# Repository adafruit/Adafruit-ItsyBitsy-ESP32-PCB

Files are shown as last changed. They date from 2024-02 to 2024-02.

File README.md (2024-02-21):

## Adafruit ItsyBitsy ESP32 8 MB Flash / 2 MB PSRAM PCB

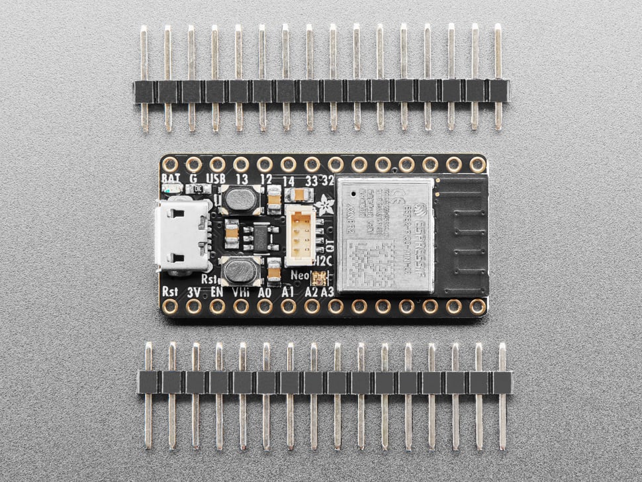
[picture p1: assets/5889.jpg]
<a href="http://www.adafruit.com/products/5889"><br/>
Click here to purchase one from the Adafruit shop</a>

PCB files for the Adafruit ItsyBitsy ESP32 8 MB Flash / 2 MB PSRAM: wFL Antenna and PCB Antenna. 

Format is EagleCAD schematic and board layout
* https://www.adafruit.com/product/5889
* https://www.adafruit.com/product/5890

### Description

What's smaller than a Feather but larger than a Trinket? It's an Adafruit ItsyBitsy ESP32, a powerful processor PCB with a plethora of pins! It features the ESP32 Pico module, an FCC-certified module that contains an ESP32 chip with dual-core 240MHz Tensilica processor, WiFi, and Bluetooth classic + BLE, configured with 8 MB of Flash memory, and 2 MB of PSRAM.

We've added some handy accessories like a USB to serial converter chip, power regulator, USB Micro B, buttons, NeoPixel, and Stemma QT I2C connector to outfit this super-hero chip for any task you want to throw it at. This is also an ultra low power ESP32 board with a deep sleep current consumption of 10uA!

At the core of the Itsy is the ESP32 (PICO ECO V3) chip, which is a single 2.4 GHz Wi-Fi and Bluetooth combo chip designed with TSMC’s 40 nm low-power technology. The ESP32 PICO in particular integrates all peripheral components seamlessly, including a crystal oscillator, flash, PSRAM, filter capacitors, and RF matching links in one single package. This makes it perfect for stuffing into a small space as the ItsyBitsy.

Please note, like other ESP32 modules, the ItsyBitsy ESP32 does not have native USB support - instead, there's a USB to serial converter chip. This means it cannot act like a USB keyboard or mouse, but it does have BLE and BT classic, so you could use it wirelessly.

Here are some of the updates you can look forward to when using ItsyBitsy ESP32:

* Same size, form-factor as the remaining ItsyBitsy mainboards - with a similar but not identical pinout (there are no pins at the end of the board like most other Itsy's due to the radio antenna being there)
* USB Micro B - To maintain compatibility with the rest of the ItsyBitsy's
* ESP32 V2 03 Dual Core 240MHz Xtensa processor - the ESP32 you know and love, with the latest engineering fixes. Massive user base and thousands of existing projects and libraries to use.
* WiFi, Bluetooth LE, and BT Classic for any IoT project usage
* 8 MB Flash & 2 MB PSRAM
* USB to Serial converter built-in with high-speed UART for debugging and uploading, auto-reset circuit works perfectly with any ESP32 uploading tool.
* Can be used with Arduino IDE, CircuitPython or MicroPython
* Built-in RGB NeoPixel LED with power control to reduce quiescent power in deep sleep
* Built-in Red LED on pin D13
* 5V level-shifted output on D5, perfect for driving NeoPixels or other devices that want 5V logic signal
* Battery input pads on the underside with diode protection for external battery packs up to 6V input
* 20 General Purpose "IO" pins:
	* 20 Pads expose pins from the ESP32:
	* 3 are analog input only (A3, A4, A5)
	* 1 is digital output only (5) with 5V level shifted up
	* 13 x 12-bit analog inputs (A0, A1, A2, A3, A4, A5, D12, D13, D14, SDA, SCL, D32, D33)
	* Dual 8-bit analog output DACs on A0/A1
	* PWM outputs on any pin
	* I2C port with STEMMA QT plug-n-play connector - a second I2C port can be defined on any other pins.
	* Hardware UART in addition to the USB-serial UART
	* Hardware SPI on the high speed SPI peripheral pins - a second SPI port can be defined on any other pins.
	* Hardware I2S on any pins
	* 8 x Capacitive Touch with no additional components required
* 3.3V regulator with 600mA peak output
* Light sleep at 4mA, deep sleep at ~10uA
* Reset switch for starting your project code over, for entering bootloader mode or for user reading
* User switch on pin 35
* Really small

Each order comes with one assembled and tested ItsyBitsy ESP32 with headers that can be soldered in for use with a breadboard.

### License

Adafruit invests time and resources providing this open source design, please support Adafruit and open-source hardware by purchasing products from [Adafruit](https://www.adafruit.com)!

Designed by Limor Fried/Ladyada for Adafruit Industries.

Creative Commons Attribution/Share-Alike, all text above must be included in any redistribution. 
See license.txt for additional details.

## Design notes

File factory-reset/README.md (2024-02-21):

## Factory Reset file - ItsyBitsy ESP32 8 MB Flash / 2 MB PSRAM

This is the factory reset file for the ItsyBitsy ESP32 8 MB Flash / 2 MB PSRAM.

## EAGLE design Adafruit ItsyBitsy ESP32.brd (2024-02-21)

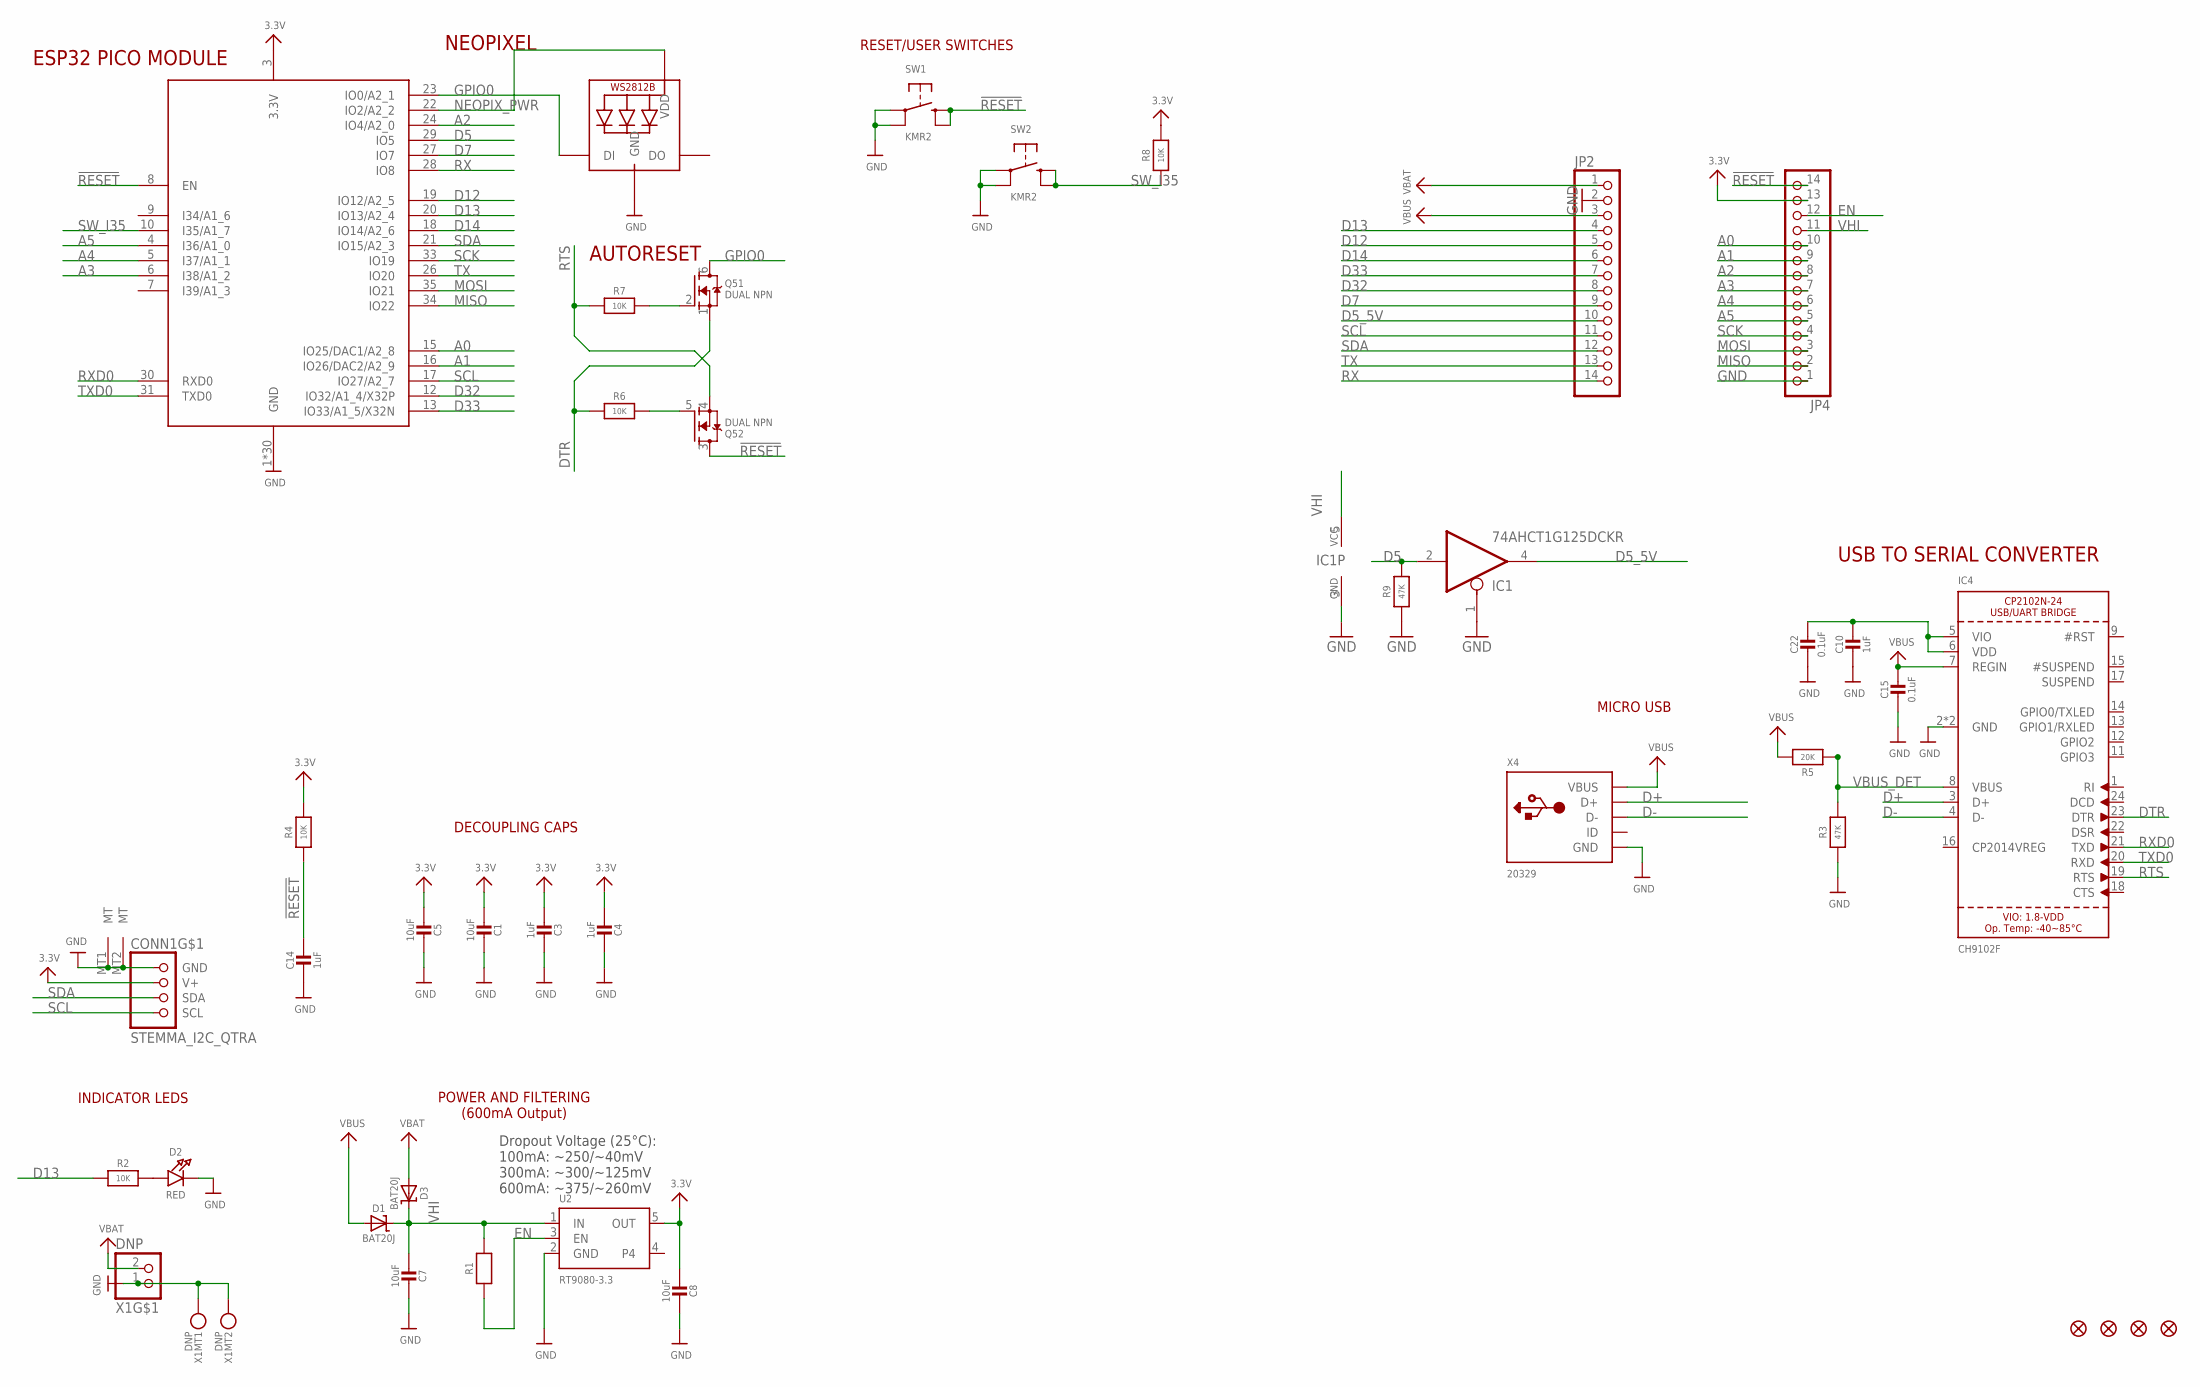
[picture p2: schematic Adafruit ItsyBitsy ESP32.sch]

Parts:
C1, C5, C7, C8: 10uF; 0805-NO
C3, C4, C10, C14: 1uF; 0603-NO
C15, C22: 0.1uF; 0603-NO
CONN1: STEMMA_I2C_QTRA; JST_SH4_RA
D1, D3: BAT20J; SOD-323
D2: RED; CHIPLED_0603_NOOUTLINE
FID1, FID2, FID3, FID4: FIDUCIAL_1MM
IC1: 74AHCT1G125DCKR; SC70-5
IC4: CH9102F; QFN24_4MM_SMSC
JP2, JP4: HEADER-1X14; 1X14_ROUND70
LED2: WS2812B_SK6805_1515; SK6805_1515
Q5: DUAL NPN; SOT363; JLC_ROTATION 0
R1, R2, R4, R6, R7, R8: 10K; 0603-NO
R3, R9: 47K; 0603-NO
R5: 20K; 0603-NO
SW1, SW2: KMR2; BTN_RKB2_4.6X2.8
U2: RT9080-3.3; SOT23-5; JLC_ROTATION 0
X1: DNP; JSTPH2_BATT
X3: ESP32-PICO-MINI-02MINI; ESP32-PICO-MINI
X4: 20329; 4UCONN_20329_SLIM

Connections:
3.3V: C1.2, C3.2, C4.2, C5.2, C8.2, CONN1.2 (V+), JP4.13, R4.2, R8.2, U2.5 (OUT), X3.3 (3.3V)
3.45V: C10.1, C22.1, IC4.5 (VIO), IC4.6 (VDD)
!RESET: C14.1, JP4.14, Q5.3 (D), R4.1, SW1.B (S), SW1.B' (S1), X3.8 (EN)
A0: JP4.10, X3.15 (IO25/DAC1/A2_8)
A1: JP4.9, X3.16 (IO26/DAC2/A2_9)
A2: JP4.8, X3.24 (IO4/A2_0)
A3: JP4.7, X3.6 (I38/A1_2)
A4: JP4.6, X3.5 (I37/A1_1)
A5: JP4.5, X3.4 (I36/A1_0)
D5: IC1.2 (I), R9.2, X3.29 (IO5)
D5_5V: IC1.4 (O), JP2.10
D7: JP2.9, X3.27 (IO7)
D12: JP2.5, X3.19 (IO12/A2_5)
D13: JP2.4, R2.1, X3.20 (IO13/A2_4)
D14: JP2.6, X3.18 (IO14/A2_6)
D32: JP2.8, X3.12 (IO32/A1_4/X32P)
D33: JP2.7, X3.13 (IO33/A1_5/X32N)
D+: IC4.3 (D+), X4.D+
D-: IC4.4 (D-), X4.D-
DTR: IC4.23 (DTR), Q5.1 (S), R6.1
EN: JP4.12, R1.1, U2.3 (EN)
GND: C1.1, C3.1, C4.1, C5.1, C7.1, C8.1, C10.2, C14.2, C15.2, C22.2, CONN1.1 (GND), CONN1.MT1 (MT), CONN1.MT2 (MT), D2.C, IC1.1 (OE), IC1.3 (GND), IC4.2 (GND), IC4.THERM (GND), JP2.2, JP4.1, LED2.4 (GND), R3.1, R9.1, SW1.A, SW1.A' (P1), SW2.A, SW2.A' (P1), U2.2 (GND), X1.1, X1.NC1, X1.NC2, X3.1 (GND), X3.2 (GND), X3.11 (GND), X3.14 (GND), X3.36 (GND), X3.37 (GND), X3.38 (GND), X3.39 (GND), X3.40 (GND), X3.41 (GND), X3.42 (GND), X3.43 (GND), X3.44 (GND), X3.45 (GND), X3.46 (GND), X3.47 (GND), X3.48 (GND), X3.49 (GND), X3.50 (GND), X3.51 (GND), X3.52 (GND), X3.53 (GND), X3.54 (GND), X3.55 (GND), X3.56 (GND), X3.57 (GND), X3.58 (GND), X3.59 (GND), X3.60 (GND), X3.61 (GND), X4.BASE@1 (GND), X4.BASE@2 (GND), X4.GND, X4.SPRT@1 (GND), X4.SPRT@2 (GND), X4.SPRT@3 (GND), X4.SPRT@4 (GND)
GPIO0: LED2.1 (DI), Q5.6 (D), X3.23 (IO0/A2_1)
MISO: JP4.2, X3.34 (IO22)
MOSI: JP4.3, X3.35 (IO21)
unnamed: D2.A, R2.2
unnamed: Q5.5 (G), R6.2
unnamed: Q5.2 (G), R7.2
NEOPIX_PWR: LED2.2 (VDD), X3.22 (IO2/A2_2)
RTS: IC4.19 (RTS), Q5.4 (S), R7.1
RX: JP2.14, X3.28 (IO8)
RXD0: IC4.21 (TXD), X3.30 (RXD0)
SCK: JP4.4, X3.33 (IO19)
SCL: CONN1.4 (SCL), JP2.11, X3.17 (IO27/A2_7)
SDA: CONN1.3 (SDA), JP2.12, X3.21 (IO15/A2_3)
SW_I35: R8.1, SW2.B (S), SW2.B' (S1), X3.10 (I35/A1_7)
TX: JP2.13, X3.26 (IO20)
TXD0: IC4.20 (RXD), X3.31 (TXD0)
VBAT: D3.A, JP2.1, X1.2
VBUS: C15.1, D1.A, IC4.7 (REGIN), JP2.3, R5.2, X4.VBUS
VBUS_DET: IC4.8 (VBUS), R3.2, R5.1
VHI: C7.2, D1.C, D3.C, IC1.5 (VCC), JP4.11, R1.2, U2.1 (IN)

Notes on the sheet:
POWER AND FILTERING (600mA Output)
Dropout Voltage (25°C): 100mA: ~250/~40mV 300mA: ~300/~125mV 600mA: ~375/~260mV
INDICATOR LEDS
RESET/USER SWITCHES
DECOUPLING CAPS
MICRO USB
ESP32 PICO MODULE
AUTORESET
NEOPIXEL
USB TO SERIAL CONVERTER

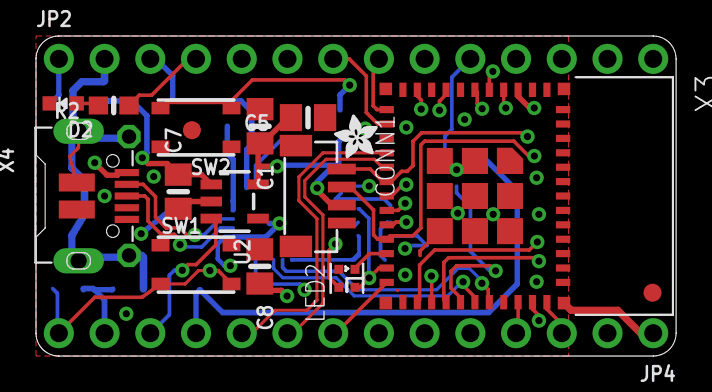
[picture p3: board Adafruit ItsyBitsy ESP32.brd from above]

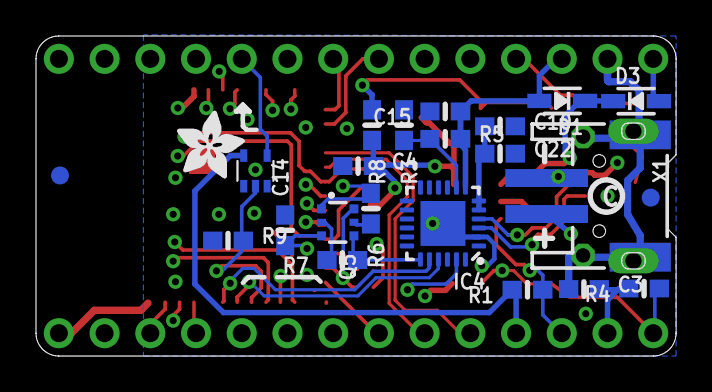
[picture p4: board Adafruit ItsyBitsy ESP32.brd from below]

Board: 4 copper layers, 35.6 x 17.8 mm, 87 parts (48 on the bottom side), 42 nets.

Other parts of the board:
E$1: ADAFRUIT_2.5MM
E$2: ADAFRUIT_3.5MM
PLABEL0: PLABEL0
PLABEL1: PLABEL1
PLABEL2: PLABEL2
PLABEL3: PLABEL3
PLABEL4: PLABEL4
PLABEL5: PLABEL5
PLABEL6: PLABEL6
PLABEL7: PLABEL7
PLABEL8: PLABEL8
PLABEL9: PLABEL9
PLABEL10: PLABEL10
PLABEL11: PLABEL11
PLABEL12: PLABEL12
PLABEL13: PLABEL13
PLABEL14: PLABEL14
PLABEL15: PLABEL15
PLABEL16: PLABEL16
PLABEL17: PLABEL17
PLABEL18: PLABEL18
PLABEL19: PLABEL19
PLABEL20: PLABEL20
PLABEL21: PLABEL21
PLABEL22: PLABEL22
PLABEL23: PLABEL23
PLABEL24: PLABEL24
PLABEL25: PLABEL25
PLABEL26: PLABEL26
PLABEL27: PLABEL27
PLABEL28: PLABEL28
PLABEL29: PLABEL29
PLABEL30: PLABEL30
PLABEL31: PLABEL31
PLABEL32: PLABEL32
PLABEL33: PLABEL33
PLABEL34: PLABEL34
PLABEL35: PLABEL35
PLABEL36: PLABEL36
PLABEL37: PLABEL37
PLABEL38: PLABEL38
PLABEL39: PLABEL39
PLABEL40: PLABEL40
PLABEL41: PLABEL41
PLABEL42: PLABEL42
PLABEL43: PLABEL43
PLABEL44: PLABEL44
U$16: PCBFEAT-REV-040

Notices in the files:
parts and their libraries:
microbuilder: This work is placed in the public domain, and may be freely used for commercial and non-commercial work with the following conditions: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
